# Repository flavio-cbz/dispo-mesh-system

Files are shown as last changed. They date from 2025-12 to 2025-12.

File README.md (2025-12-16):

# 📡 DispoMesh - Système de Disponibilité Connecté

  

**DispoMesh** est une solution intelligente et autonome pour visualiser en temps réel la disponibilité des collaborateurs dans un open-space ou des bureaux partagés. Fini les interruptions inutiles : un coup d'œil suffit pour savoir si votre collègue est disponible, occupé ou absent.

---

## ❓ La Problématique

Dans les écoles et laboratoires, les **enseignants-chercheurs** travaillant en open-space sont fréquemment sollicités par les étudiants, souvent au détriment de leur concentration.

* *"Est-ce que je peux entrer pour poser une question ?"*
* *"Le professeur est-il en pleine recherche ou disponible ?"*
* *"Est-il en réunion ou simplement concentré ?"*

Ces interruptions constantes par les élèves nuisent à la productivité et à la qualité du travail de recherche. Ça nuit à leur travail et ainsi qu'à tous les autres s'il n'est pas là.

---

## 🎯 Objectif du Projet

Créer un système **simple, visuel et décentralisé** permettant à chaque collaborateur d'indiquer son statut via un petit boîtier sur son bureau. Ces informations sont instantanément répercutées sur un **tableau de bord central** (mur d'écrans OLED) et une **interface web**.

### Les 3 États Clés

* 🟢 **DISPONIBLE** : "Vous pouvez venir me voir."
* 🔴 **OCCUPÉ** : "Je suis concentré / en réunion, ne pas déranger."
* 🟠 **ABSENT** : "Je ne suis pas à mon poste."

---

## 🏗️ Architecture & Fonctionnement

Le système repose sur un réseau **WiFi Mesh** (maillé) autonome. Il ne nécessite pas de connexion Internet ni d'infrastructure complexe.

### 1. Les Boîtiers "Slave" (Sur les bureaux)

Chaque collaborateur dispose d'un petit boîtier autonome.

* **Action** : Un simple bouton pour changer de statut.
* **Feedback** : Une LED (Verte/Rouge/Orange) et un petit écran confirment le statut actuel.
* **Intelligence** : Si vous oubliez de vous mettre en "Absent", le boîtier passe automatiquement en **Mode Éco** après 5 minutes d'inactivité.
* **Configuration facile** : Au premier démarrage, le boîtier crée un WiFi de config. Après configuration, il se connecte automatiquement au réseau.
* **Reset sans ordinateur** : Maintenir le bouton 5 secondes au démarrage pour réinitialiser la configuration.

### 2. Le Boîtier "Master" (À l'entrée ou au mur)

C'est le cerveau du système.

* **Affichage** : Un mur d'écrans OLED affiche la liste de tous les collaborateurs et leur statut en temps réel.
* **Dashboard Web** : Héberge un site web local accessible par tous pour voir les disponibilités depuis son smartphone ou PC.
* **Animation** : Effets visuels fluides et indicateurs LED pour une lecture rapide.

---

## ✨ Fonctionnalités Clés

* **🚀 Plug & Play** : Branchez, ça marche. Le réseau se crée tout seul.
* **⚡ Temps Réel** : Changement de statut instantané (< 100ms).
* **🔋 Économie d'Énergie** : Mise en veille automatique des écrans et processeurs.
* **📱 Interface Web Moderne** : Dark mode, responsive, QR Code pour connexion facile.
* **🛡️ Robuste** : Redémarrage automatique en cas de bug (Watchdog), reconnexion automatique au réseau.

---

## 🛠️ Comment le refaire chez soi ?

### Matériel Requis

Pour un kit de démarrage (1 Master + 1 Slave) :

* **2x ESP32 DevKit V1** (ou compatible).
* **5x Écrans OLED SSD1306** (128x32 pixels, I2C).
* **1x Multiplexeur I2C TCA9548A** (pour le Master, permet de brancher plusieurs écrans même adresse).
* **Ruban LED NeoPixel (WS2812B)** (au moins 6 LEDs).
* **1x Bouton Poussoir** (pour le Slave).
* **Câbles Dupont** et Breadboards.

### Câblage

#### 🔌 Master (Récepteur)

* **Écrans OLED** : Via le Multiplexeur TCA9548A (Adresse 0x70).
  * SDA ESP32 (D21) -> SDA TCA
  * SCL ESP32 (D22) -> SCL TCA
  * Écrans sur les canaux TCA : 0, 1, 2, 6, 7.
* **LEDs NeoPixel** : Pin **D27**.

#### 🔌 Slave (Émetteur)

* **Écran OLED** : Directement sur I2C.
  * SDA -> D21
  * SCL -> D22
* **Bouton** : Pin **D32** (avec Pull-down interne ou externe).
* **LED NeoPixel** : Pin **D27**.

### Installation Logicielle

#### Option A : Via PlatformIO (Recommandé)

1. **Pré-requis** :
   * [VS Code](https://code.visualstudio.com/)
   * Extension **PlatformIO IDE** pour VS Code.

2. **Cloner le projet** :

    ```bash
    git clone https://github.com/flavio-cbz/dispo-mesh-system.git
    cd dispo-mesh-system
    ```

3. **Bibliothèques (Gérées automatiquement par PlatformIO)** :
   * `painlessMesh` (v1.5.7)
   * `ArduinoJson` (v7.4.2)
   * `Adafruit SSD1306` (v2.5.9)
   * `Adafruit GFX Library` (v1.11.9)
   * `Adafruit NeoPixel` (v1.12.0)
   * `U8g2_for_Adafruit_GFX` (v1.0.2)

4. **Déployer** :
    Connectez vos ESP32 et utilisez le script de déploiement ou les tâches PlatformIO "Upload".

    ```bash
    ./deploy.sh
    ```

    Suivez les instructions à l'écran pour flasher le Master puis les Slaves.

#### Option B : Via Arduino IDE (Manuel)

Si vous préférez l'IDE Arduino classique :

1. Installez les bibliothèques listées ci-dessus via le **Gestionnaire de bibliothèques**.
2. Ouvrez `master_recepteur/src/master_recepteur.ino` pour le Master.
3. Ouvrez `slave_emetteur/src/slave_emetteur.ino` pour les Slaves.
4. Sélectionnez votre carte (ESP32 Dev Module) et le port, puis téléversez.

### 🖨️ Fichiers 3D à Imprimer

Les fichiers STL pour l'impression 3D des boîtiers sont disponibles dans le dossier `Modélisations 3D/` :

#### Émetteur (Slave)
* **[Emetteur_Base.STL](Modélisations%203D/Emetteur/Emetteur_Base.STL)** : Socle du boîtier émetteur.
* **[Emetteur_Boite.STL](Modélisations%203D/Emetteur/Emetteur_Boite.STL)** : Couvercle du boîtier émetteur.

#### Récepteur (Master)
* **[Recepteur_MAIN.STL](Modélisations%203D/Recepteur/Recepteur_MAIN.STL)** : Corps principal du récepteur.
* **[Recepteur_Add.STL](Modélisations%203D/Recepteur/Recepteur_Add.STL)** : Pièce additionnelle pour le récepteur.

> 💡 Les fichiers sources SolidWorks sont également disponibles dans `Modélisations 3D/Fichier Solidworks/`.

### 📸 Galerie

#### L'Émetteur (Slave)

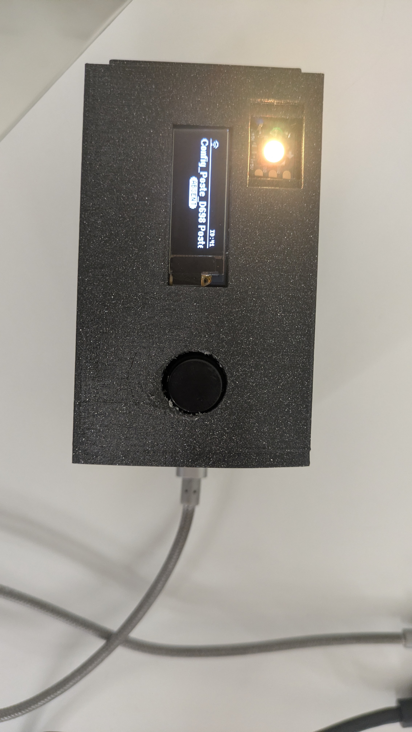
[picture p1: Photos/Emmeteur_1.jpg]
Emetteur Slave

*Le boîtier Slave avec son bouton et son écran de statut.*

#### Le Récepteur (Master)

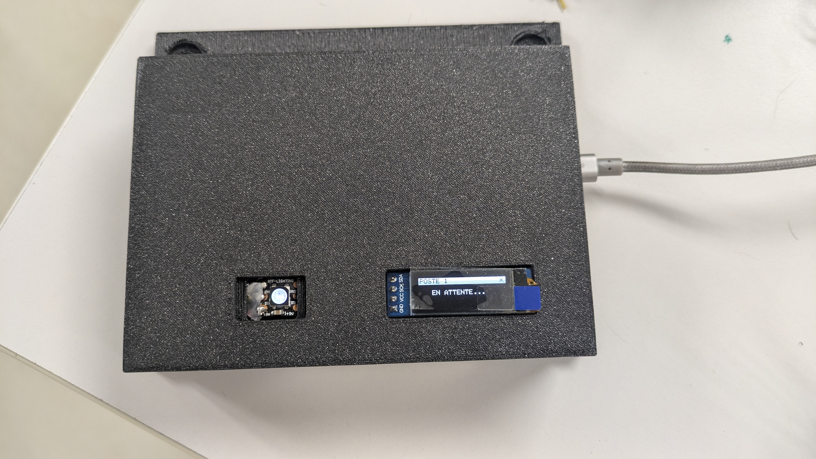
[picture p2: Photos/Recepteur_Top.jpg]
Récepteur Master

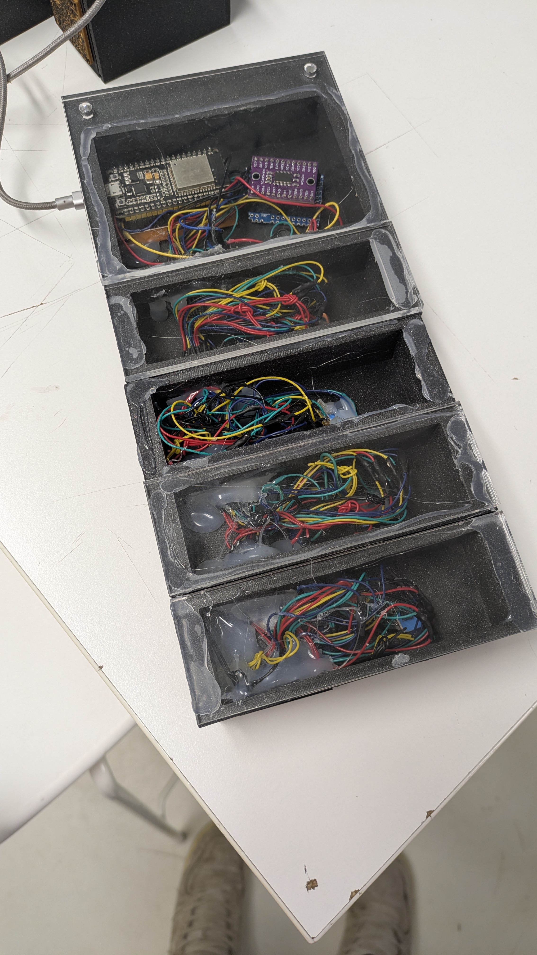
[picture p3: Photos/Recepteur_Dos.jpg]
Câblage Arrière

*Le Master et son câblage (Multiplexeur I2C visible à l'arrière).*

#### Montage Complet

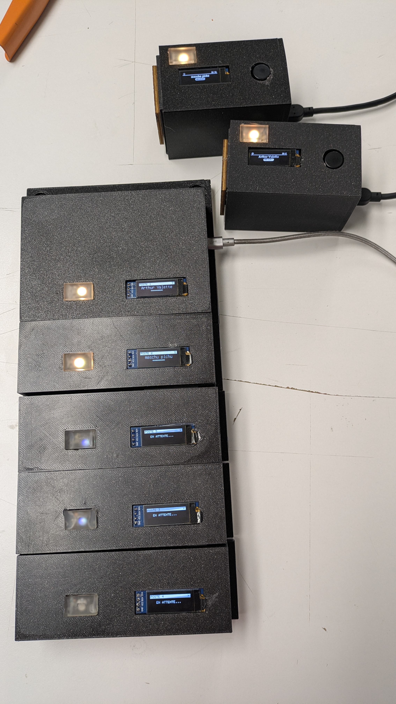
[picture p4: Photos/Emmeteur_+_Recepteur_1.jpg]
Système Complet

*Vue d'ensemble du système DispoMesh en fonctionnement.*

### 🎥 Démos Vidéo

#### Fonctionnement Général

<video src="Photos/Demo_courte_recepteur.mp4" controls width="100%"></video>

#### Démonstration du Reset

<video src="Photos/Demo_Reset.mp4" controls width="100%"></video>

4. **Profiter !**
    Les boîtiers se connectent entre eux automatiquement. Connectez-vous au WiFi `DispoMesh` (mot de passe: `meshpass2025`) pour accéder au dashboard.

---

## 📚 Documentation

* Pour les détails techniques approfondis (architecture code, protocole JSON, hardware), consultez la [Documentation Technique](DOCUMENTATION_TECHNIQUE.md).

---

## 📄 Licence

Ce projet est open-source sous licence **MIT**. Sentez-vous libre de le modifier, l'améliorer et le partager !

---
*Développé par Flavio COMBLEZ pour simplifier la vie de bureau.*

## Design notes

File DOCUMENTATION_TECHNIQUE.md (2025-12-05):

# Documentation Technique - DispoMesh v6.0

## 1. Vue d'Ensemble du Système

**DispoMesh** est un système de signalétique de disponibilité distribué basé sur des microcontrôleurs ESP32 communiquant via un réseau maillé (Mesh).

Le système est composé de deux types d'unités :

1. **Le Master (Récepteur)** : Unité centrale qui agrège les données, héberge le tableau de bord web et affiche les statuts sur un mur d'écrans OLED.
2. **Les Slaves (Émetteurs)** : Boîtiers individuels placés sur les bureaux, permettant aux utilisateurs de changer leur statut via un bouton physique.

### Architecture Logique

```mermaid
graph TD
    S1[Slave 1] <-->|Mesh JSON| M[Master Node]
    S2[Slave 2] <-->|Mesh JSON| M
    S3[Slave 3] <-->|Mesh JSON| M
    M -->|I2C Multiplexé| D[Mur d'Écrans OLED]
    M -->|HTTP/REST| W[Dashboard Web]
    U[Utilisateur] -->|Bouton| S1
```

---

## 2. Le Nœud Maître (Master Récepteur)

Le Master est le cerveau du système. Il est configuré comme le nœud **ROOT** du réseau maillé, ce qui stabilise la topologie du réseau.

### 2.1 Gestion des Écrans (Multiplexage I2C)

Le Master gère jusqu'à 5 écrans OLED simultanément. Comme les écrans OLED ont tous la même adresse I2C (`0x3C`), un multiplexeur **TCA9548A** est utilisé.

* **Fichier** : `master_recepteur.ino`
* **Fonction clé** : `tcaSelect(uint8_t i)`
* **Logique** : Avant chaque commande de dessin, le code sélectionne le canal I2C approprié sur le multiplexeur.
* **Hot-Plug** : La fonction `checkScreens()` vérifie périodiquement (toutes les 5s) la présence physique des écrans pour éviter de bloquer le bus I2C si un écran est débranché.

### 2.2 Serveur Web & Interface (SPIFFS)

L'interface utilisateur n'est pas codée en dur dans le C++. Elle est stockée dans la mémoire flash du système de fichiers (SPIFFS).

* **Structure** :
  * `/index.html` : Structure HTML5 moderne.
  * `/style.css` : Styles "Glassmorphism" et animations.
  * `/script.js` : Logique frontend (récupération des données API).
* **API REST** : Le Master expose l'endpoint `/api/data` qui renvoie un JSON complet contenant l'état de tous les slots, l'historique et l'uptime.

### 2.3 Robustesse & Watchdog

Pour garantir un fonctionnement 24/7 :

* **Hardware Watchdog** : Si la boucle principale (`loop`) se bloque plus de 10 secondes, l'ESP32 redémarre automatiquement.
* **Heartbeat Monitor** : Le Master surveille les battements de cœur des Slaves. Si un Slave ne donne pas signe de vie pendant 60 secondes (`HEARTBEAT_TIMEOUT_MS`), il est marqué comme déconnecté.

### 2.4 Économiseur d'Écran (Screen Saver)

Pour éviter le marquage des écrans OLED (burn-in) et réduire la consommation :

* Si aucune activité (message Mesh reçu ou appel API) n'est détectée pendant 10 minutes, les écrans s'éteignent et les LEDs diminuent d'intensité.
* Le réveil est instantané au moindre événement.

---

## 3. Le Nœud Esclave (Slave Émetteur)

Le Slave est conçu pour être autonome et économe en énergie.

### 3.1 Initialisation & Configuration

Le Slave possède deux modes de démarrage selon son état de configuration :

#### Mode Configuration (Premier démarrage ou après reset)

Si le Slave **n'est pas configuré** :

* 🔵 LED bleue clignotante
* Écran affiche "MODE CONFIG" avec le SSID WiFi
* Un point d'accès WiFi visible est créé (`Config_Poste_XXXX`)
* **Le mesh NE démarre PAS** - pas de connexion au Master
* Après configuration via l'interface web → redémarrage automatique

#### Mode Normal

Si le Slave **est déjà configuré** :

* Démarrage normal avec connexion au mesh
* Panneau de configuration WiFi masqué

#### Reset de la Configuration

Pour **réinitialiser** un Slave (équivalent à un re-upload du code) :

1. Maintenir le **bouton enfoncé pendant 5 secondes au démarrage**
2. 🟠 LED orange clignotante + compte à rebours sur l'écran
3. Après 5 secondes : 🟣 LED magenta + "CONFIG RESET!"
4. La configuration est effacée et le Slave passe en mode configuration

> **Note** : Cette fonctionnalité permet de reconfigurer un Slave sur le terrain sans ordinateur.

### 3.2 Gestion des États

L'utilisateur change son statut via un bouton poussoir unique.

* **États** : Disponible (Vert) -> Occupé (Rouge) -> Absent (Orange).
* **Feedback** : Une LED NeoPixel et un écran OLED local confirment l'état.

### 3.3 Mode Éco (Deep Power Saving)

Si l'utilisateur reste en statut "ABSENT" pendant plus de 5 minutes, le Slave entre en mode économie d'énergie agressif :

1. **CPU Downclocking** : La fréquence du processeur passe de 240MHz à 80MHz.
2. **WiFi Power Save** : Activation du mode `WIFI_PS_MIN_MODEM`.
3. **Dimming** : La luminosité des LEDs est réduite au minimum.

### 3.4 Communication

* **Heartbeat** : Envoie un message `heartbeat` toutes les 30 secondes pour dire au Master "Je suis vivant".
* **Broadcast** : Envoie un message `status` immédiatement lors d'un appui bouton.

---

## 4. Protocole de Communication (JSON)

Les échanges se font via des paquets JSON légers sur le réseau `painlessMesh`.

### Types de Messages

**1. Enregistrement (`register`)**
Envoyé par le Slave au démarrage pour s'associer à un slot.

```json
{
  "type": "register",
  "prenom": "Jean",
  "nom": "Dupont",
  "etat": 0
}
```

**2. Mise à jour de Statut (`status`)**
Envoyé lors d'un appui bouton.

```json
{
  "type": "status",
  "etat": 1
}
```

**3. Battement de Cœur (`heartbeat`)**
Envoyé périodiquement.

```json
{
  "type": "heartbeat",
  "slotId": 2,
  "etat": 1,
  "eco": false
}
```

---

## 5. Guide de Déploiement

Un script automatisé `deploy.sh` facilite la mise à jour des boîtiers.

### Pré-requis

* PlatformIO Core (CLI) installé.
* Drivers USB-Série (CH340 ou CP210x) installés.

### Procédure

1. Connecter le Master en USB.
2. Lancer `./deploy.sh`.
3. Sélectionner le port du Master. Le script va :
    * Créer l'image du système de fichiers (SPIFFS) avec les fichiers web.
    * Téléverser le SPIFFS.
    * Compiler et téléverser le Firmware.
4. Connecter ensuite les Slaves un par un et suivre les instructions du script.

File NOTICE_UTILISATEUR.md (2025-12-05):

# 📋 Notice d'Utilisation

## Votre boîtier de disponibilité

---

## 🎨 Les 3 états

| Couleur | Signification |
|---|---|
| 🟢 **Vert** | Je suis disponible |
| 🔴 **Rouge** | Ne pas déranger |
| 🟠 **Orange** | Je suis absent |

---

## 🔘 Changer votre statut

**Appuyez sur le bouton** pour passer à l'état suivant.

---

## Première utilisation

1. L'écran affiche **"MODE CONFIG"** avec un nom de réseau WiFi
2. Connectez-vous à ce WiFi depuis votre téléphone
3. Mot de passe : **config2025**
4. Entrez votre **Prénom** et **Nom** dans la page qui s'affiche
5. Le boîtier redémarre : c'est prêt !

---

## Changer de nom

Pour reconfigurer le boîtier :

1. Débranchez-le
2. Maintenez le bouton appuyé
3. Rebranchez en gardant le bouton enfoncé **5 secondes**
4. Le boîtier se réinitialise, recommencez la configuration

---

*En cas de problème, contactez votre administrateur.*

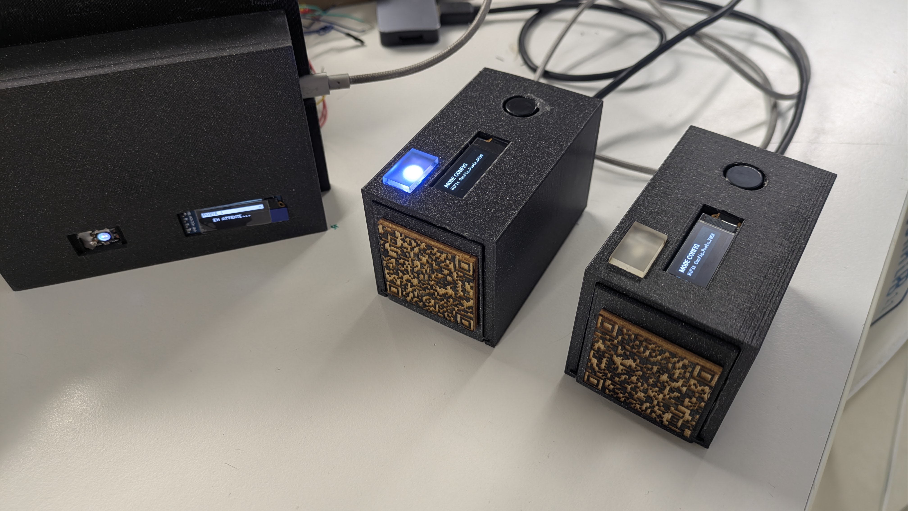
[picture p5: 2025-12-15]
Photos/Pres_1.jpg

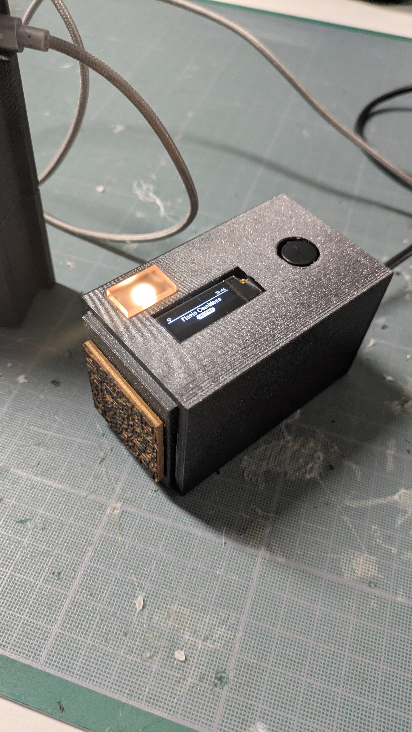
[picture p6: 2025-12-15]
Photos/Emmeteur_2.jpg

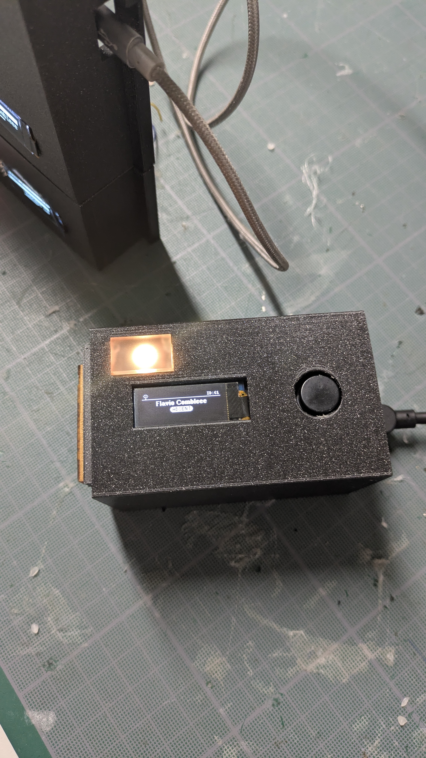
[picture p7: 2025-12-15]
Photos/Emmeteur_3.jpg

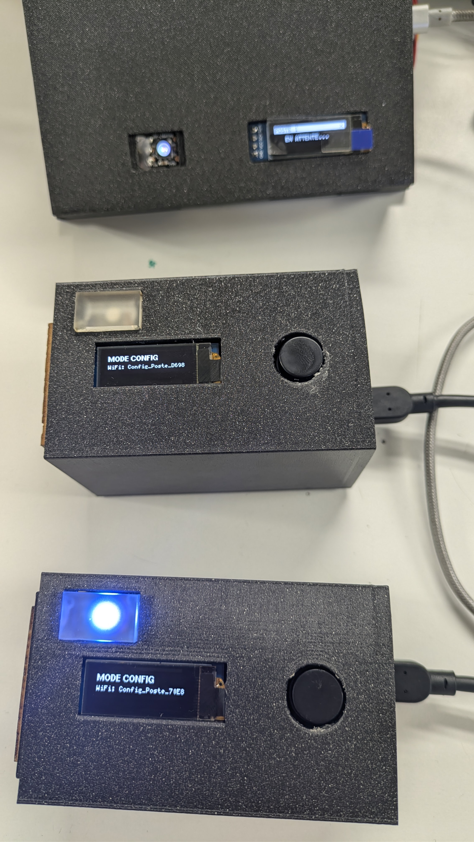
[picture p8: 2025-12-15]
Photos/Emmeteur_+_Recepteur_3.jpg

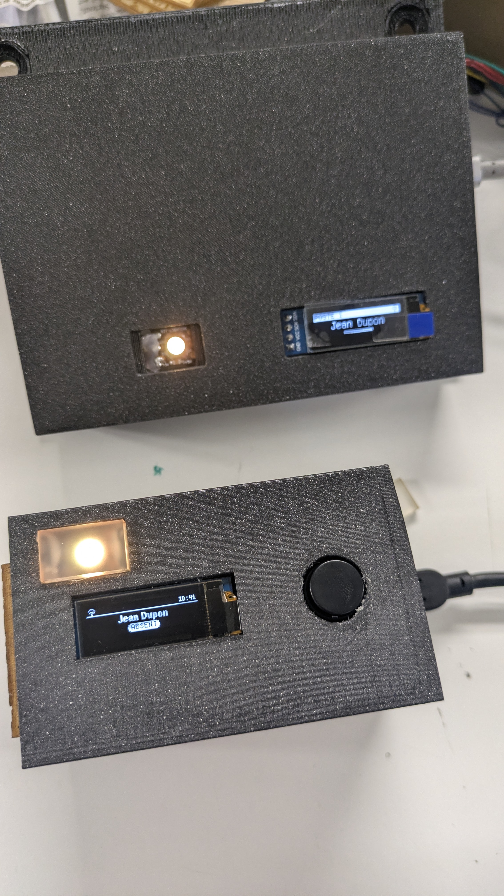
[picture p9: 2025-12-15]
Photos/Emmeteur_+_Recepteur_4.jpg

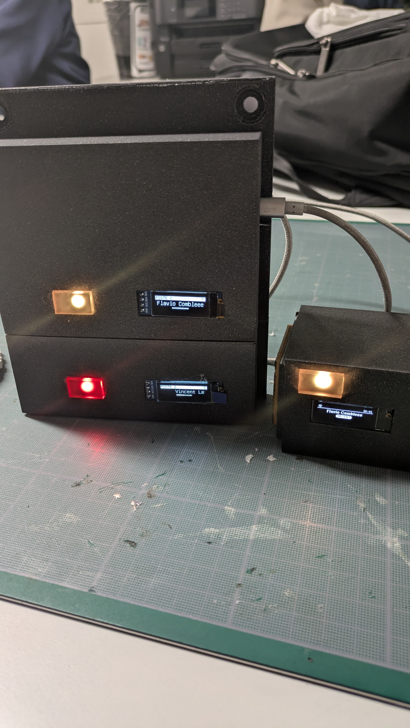
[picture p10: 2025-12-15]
Photos/Emmeteur_+_Recepteur_2.jpg

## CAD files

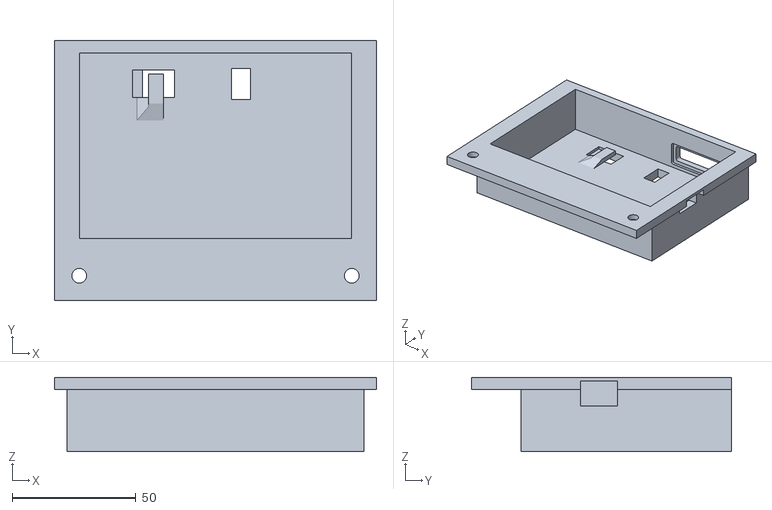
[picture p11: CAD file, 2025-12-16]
Modélisations 3D/Recepteur/Recepteur_MAIN.STL
130.0 x 105.0 x 30.0

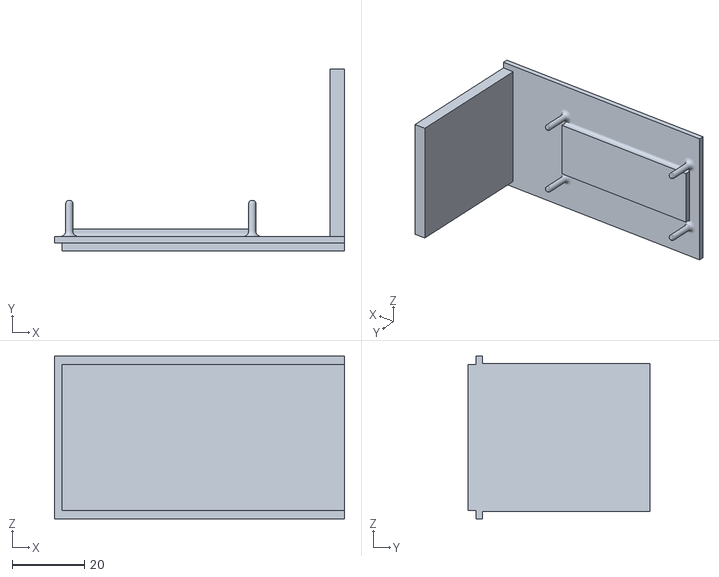
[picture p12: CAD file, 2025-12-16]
Modélisations 3D/Emetteur/Emetteur_Base.STL
80.2 x 50.3 x 45.0

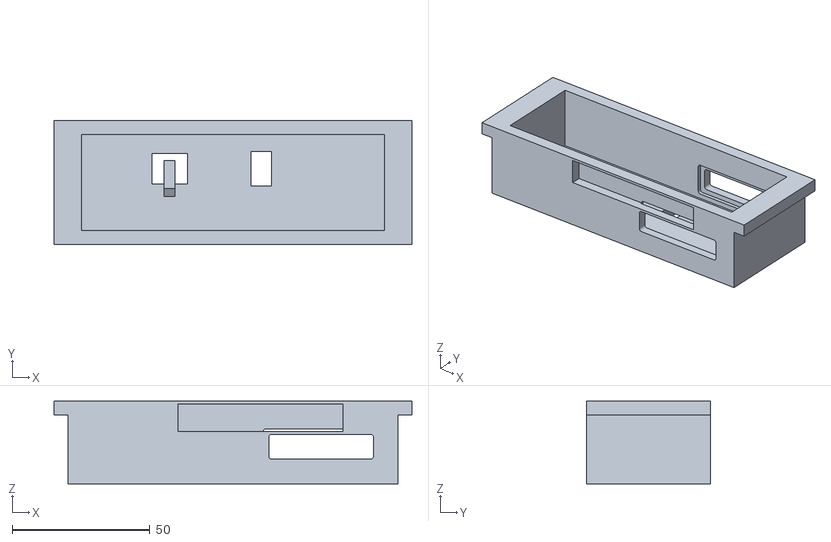
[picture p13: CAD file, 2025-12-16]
Modélisations 3D/Recepteur/Recepteur_Add.STL
130.0 x 45.0 x 30.0

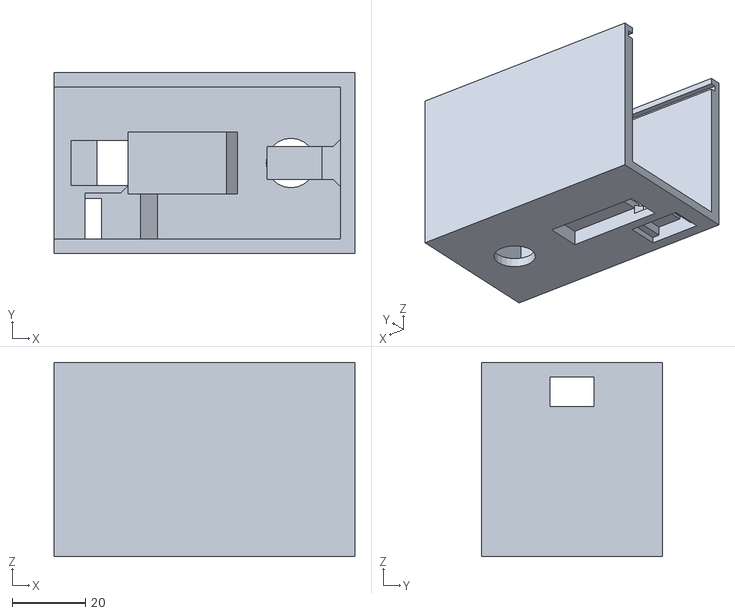
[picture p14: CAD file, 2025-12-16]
Modélisations 3D/Emetteur/Emetteur_Boite.STL
82.2 x 49.5 x 53.0

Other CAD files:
Modélisations 3D/Fichier Solidworks/Piece 1.SLDPRT
Modélisations 3D/Fichier Solidworks/Piece 2.SLDPRT
Modélisations 3D/Fichier Solidworks/Piece 4.SLDPRT
Modélisations 3D/Fichier Solidworks/Piece 3.SLDPRT

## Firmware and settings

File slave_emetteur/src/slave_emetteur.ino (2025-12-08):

/*
 * ═══════════════════════════════════════════════════════════════════════
 * ESP32 SLAVE ÉMETTEUR - DispoMesh v5.7 FINAL - FIX INIT & CONFIG
 * ═══════════════════════════════════════════════════════════════════════
 * - BROWNOUT : DÉSACTIVÉ (Stabilité)
 * - WIFI : MASQUÉ (Variable HIDE_NETWORKS = 1)
 * - UI : Badge iOS + Icônes
 * - RESEAU : Dual Stack (Mesh + Config AP) sur même canal
 * ═══════════════════════════════════════════════════════════════════════
 */

#include <Adafruit_NeoPixel.h>
#include <Adafruit_SSD1306.h>
#include <ArduinoJson.h>
#include <DNSServer.h>
#include <SPIFFS.h>
#include <U8g2_for_Adafruit_GFX.h>
#include <WebServer.h>
#include <WiFi.h>
#include <Wire.h>
#include <painlessMesh.h>

// MODULES CRITIQUES (Anti-Brownout)
#include "soc/rtc_cntl_reg.h"
#include "soc/soc.h"

// MODULES ÉCONOMIE D'ÉNERGIE
#include "esp_wifi.h"
#include <esp_pm.h>
#include <esp_task_wdt.h>

// 🔒 CONFIGURATION SÉCURITÉ
#define HIDE_NETWORKS 1 // 1 = Masqué, 0 = Visible

// ⚡ CONFIGURATION ÉCONOMIE D'ÉNERGIE
#define ECO_MODE_DELAY_MS 300000    // 5 minutes en ABSENT avant mode éco
#define HEARTBEAT_INTERVAL_MS 30000 // Heartbeat toutes les 30 secondes
#define LED_BRIGHTNESS_NORMAL 40
#define LED_BRIGHTNESS_ECO 8
#define CPU_FREQ_NORMAL 240 // MHz
#define CPU_FREQ_ECO 80     // MHz

// CONFIGURATION MATÉRIEL
#define BTN_PIN 32
#define PIN_NEOPIXEL 27
#define NUM_PIXELS 1

#define SCREEN_WIDTH 128
#define SCREEN_HEIGHT 32
#define OLED_ADDR 0x3C

Adafruit_NeoPixel pixel(NUM_PIXELS, PIN_NEOPIXEL, NEO_GRB + NEO_KHZ800);
Adafruit_SSD1306 display(SCREEN_WIDTH, SCREEN_HEIGHT, &Wire, -1);
U8G2_FOR_ADAFRUIT_GFX u8g2;

const uint32_t COLOR_DISPO = pixel.Color(0, 255, 0);
const uint32_t COLOR_BUSY = pixel.Color(255, 0, 0);
const uint32_t COLOR_AWAY = pixel.Color(255, 140, 0);

// VARIABLES GLOBALES
#define MESH_PREFIX "DispoMesh"
#define MESH_PASSWORD "meshpass2025"
#define MESH_PORT 5555

// 🔧 CONFIGURATION RESET
#define RESET_HOLD_TIME_MS 5000 // 5 secondes pour reset config

SemaphoreHandle_t xMutex;
char apSSID[32];
String monPrenom = "Nouveau";
String monNom = "Poste";
int etatActuel = 2;
int slotId = -1;
volatile bool configSauvegardee = false;
bool meshInitialized = false;
volatile bool needsRegister = false; // Flag pour re-registration différé
bool isConfigured = false;           // Flag indiquant si le poste est configuré
bool configModeActive = false; // Flag indiquant si on est en mode configuration

// ⚡ Variables mode économie d'énergie
unsigned long lastStateChange = 0; // Timestamp du dernier changement d'état
unsigned long lastHeartbeat = 0;   // Timestamp du dernier heartbeat
bool ecoModeActive = false;        // Mode économie activé
uint8_t currentBrightness = LED_BRIGHTNESS_NORMAL;

Scheduler userScheduler;
painlessMesh mesh;
WebServer server(80);
DNSServer dnsServer;

// ═══════════════════════════════════════════════════════════════════════
// UI OLED
// ═══════════════════════════════════════════════════════════════════════
const unsigned char icon_wifi[] PROGMEM = {0x3C, 0x42, 0x81, 0x3C,
                                           0x42, 0x18, 0x00, 0x18};

void updateLocalDisplay() {
  display.clearDisplay();
  u8g2.setForegroundColor(SSD1306_WHITE);

  // Header
  display.drawLine(0, 8, SCREEN_WIDTH, 8, SSD1306_WHITE);
  if (slotId != -1)
    display.drawBitmap(2, 0, icon_wifi, 8, 8, SSD1306_WHITE);

  u8g2.setFont(u8g2_font_4x6_tr);
  String idTxt = "ID:" + String(mesh.getNodeId() % 100);
  u8g2.drawUTF8(SCREEN_WIDTH - u8g2.getUTF8Width(idTxt.c_str()) - 2, 6,
                idTxt.c_str());

  // Nom
  u8g2.setFont(u8g2_font_helvB08_tf);
  String fullName = monPrenom + " " + monNom;
  int xName = (SCREEN_WIDTH - u8g2.getUTF8Width(fullName.c_str())) / 2;
  if (xName < 0)
    xName = 0;
  u8g2.drawUTF8(xName, 20, fullName.c_str());

  // Badge Statut
  String statusTxt;
  switch (etatActuel) {
  case 0:
    statusTxt = "DISPONIBLE";
    break;
  case 1:
    statusTxt = "OCCUPE";
    break;
  default:
    statusTxt = "ABSENT";
    break;
  }

  u8g2.setFont(u8g2_font_5x7_tf);
  int wStatus = u8g2.getUTF8Width(statusTxt.c_str()) + 8;
  int xStatus = (SCREEN_WIDTH - wStatus) / 2;

  display.fillRoundRect(xStatus, 23, wStatus, 9, 4, SSD1306_WHITE);
  u8g2.setForegroundColor(SSD1306_BLACK);
  u8g2.setBackgroundColor(SSD1306_WHITE);
  u8g2.drawUTF8(xStatus + 4, 30, statusTxt.c_str());
  u8g2.setForegroundColor(SSD1306_WHITE);
  u8g2.setBackgroundColor(SSD1306_BLACK);

  display.display();
}

void updateLEDs() {
  pixel.clear();
  if (slotId == -1) {
    // Clignotement rouge quand non connecté
    if ((millis() / 500) % 2) {
      pixel.setPixelColor(0, COLOR_BUSY);
    } else {
      pixel.setPixelColor(0, 0); // OFF pour le clignotement
    }
  } else {
    switch (etatActuel) {
    case 0:
      pixel.setPixelColor(0, COLOR_DISPO);
      break;
    case 1:
      pixel.setPixelColor(0, COLOR_BUSY);
      break;
    default:
      pixel.setPixelColor(0, COLOR_AWAY);
      break;
    }
  }
  pixel.show();
}

// ═══════════════════════════════════════════════════════════════════════
// SYSTÈME
// ═══════════════════════════════════════════════════════════════════════
void initSSID() {
  // Utiliser ESP.getEfuseMac() pour obtenir une MAC stable AVANT l'init WiFi
  uint64_t chipid = ESP.getEfuseMac();
  uint8_t mac[6];
  mac[0] = (chipid >> 0) & 0xFF;
  mac[1] = (chipid >> 8) & 0xFF;
  mac[2] = (chipid >> 16) & 0xFF;
  mac[3] = (chipid >> 24) & 0xFF;
  mac[4] = (chipid >> 32) & 0xFF;
  mac[5] = (chipid >> 40) & 0xFF;

  snprintf(apSSID, sizeof(apSSID), "Config_Poste_%02X%02X", mac[4], mac[5]);
  Serial.printf("[INIT] MAC eFuse: %02X:%02X:%02X:%02X:%02X:%02X\n", mac[0],
                mac[1], mac[2], mac[3], mac[4], mac[5]);
  Serial.printf("[INIT] SSID généré: %s\n", apSSID);
}

void sauvegarderNom(String p, String n) {
  // Validation: ne pas sauvegarder si le prénom ressemble à un SSID
  if (p.startsWith("Config_Poste_") || p.length() == 0) {
    Serial.println(
        "[CONFIG] ERREUR: Tentative de sauvegarde d'un nom invalide!");
    return;
  }

  Serial.printf("[CONFIG] Sauvegarde nom: '%s' '%s'\n", p.c_str(), n.c_str());

  File f = SPIFFS.open("/config.json", "w");
  if (f) {
    StaticJsonDocument<256> doc;
    doc["p"] = p;
    doc["n"] = n;
    doc["configured"] = true; // Flag explicite de configuration
    serializeJson(doc, f);
    f.close();
    Serial.println("[CONFIG] Configuration sauvegardée avec succès");

    // Marquer comme configuré
    isConfigured = true;
  } else {
    Serial.println("[CONFIG] ERREUR: Impossible d'ouvrir le fichier config!");
  }
  updateLocalDisplay();
}

bool chargerNom() {
  Serial.println("[CONFIG] Chargement de la configuration...");

  if (SPIFFS.exists("/config.json")) {
    File f = SPIFFS.open("/config.json", "r");
    if (f) {
      StaticJsonDocument<256> doc;
      DeserializationError err = deserializeJson(doc, f);

      if (err == DeserializationError::Ok) {
        String p = doc["p"] | "";
        String n = doc["n"] | "";
        bool configured = doc["configured"] | false;

        Serial.printf("[CONFIG] Lu: prenom='%s', nom='%s', configured=%d\n",
                      p.c_str(), n.c_str(), configured);

        // Vérifier que le prénom n'est pas vide ou égal à l'SSID par défaut
        if (p.length() > 0 && !p.startsWith("Config_Poste_") &&
            !p.startsWith("Nouveau")) {
          monPrenom = p;
          monNom = n;
          f.close();
          Serial.printf("[CONFIG] Configuration valide chargée: %s %s\n",
                        monPrenom.c_str(), monNom.c_str());
          return true; // Configuration valide trouvée
        } else {
          Serial.println("[CONFIG] Prénom invalide dans la config");
        }
      } else {
        Serial.printf("[CONFIG] Erreur JSON: %s\n", err.c_str());
      }
      f.close();
    }
  } else {
    Serial.println("[CONFIG] Fichier config.json non trouvé");
  }

  // PAS de configuration valide - garder les valeurs par défaut
  // NE PAS affecter apSSID au prénom!
  monPrenom = "Nouveau";
  monNom = "Poste";
  Serial.printf(
      "[CONFIG] Pas de config valide, utilisation par défaut: %s %s\n",
      monPrenom.c_str(), monNom.c_str());
  return false; // Pas de configuration valide
}

// Fonction pour effacer la configuration
void effacerConfig() {
  if (SPIFFS.exists("/config.json")) {
    SPIFFS.remove("/config.json");
    Serial.println("[CONFIG] Configuration effacée");
  }
  // NE PAS affecter apSSID au prénom!
  monPrenom = "Nouveau";
  monNom = "Poste";
  isConfigured = false;
  Serial.printf("[CONFIG] Réinitialisé à: %s %s\n", monPrenom.c_str(),
                monNom.c_str());
}

// ═══════════════════════════════════════════════════════════════════════
// WEB SERVER
// ═══════════════════════════════════════════════════════════════════════
const char HTML_PAGE[] PROGMEM = R"rawliteral(
<!DOCTYPE html>
<html lang="fr">
<head>
    <meta charset="UTF-8">
    <meta name="viewport" content="width=device-width, initial-scale=1.0">
    <title>Configuration Poste</title>
    <style>
        body { font-family: -apple-system, BlinkMacSystemFont, "Segoe UI", Roboto, Helvetica, Arial, sans-serif; background: #1a1a2e; color: #fff; display: flex; flex-direction: column; align-items: center; min-height: 100vh; margin: 0; padding: 20px; }
        .card { background: rgba(255, 255, 255, 0.05); padding: 30px; border-radius: 20px; width: 100%; max-width: 350px; backdrop-filter: blur(10px); border: 1px solid rgba(255, 255, 255, 0.1); box-shadow: 0 8px 32px 0 rgba(0, 0, 0, 0.37); }
        h2 { margin-top: 0; font-weight: 300; letter-spacing: 1px; text-align: center; margin-bottom: 20px; }
        .input-group { margin-bottom: 15px; }
        label { display: block; margin-bottom: 5px; font-size: 0.8rem; color: rgba(255, 255, 255, 0.6); }
        input { width: 100%; padding: 12px; background: rgba(0, 0, 0, 0.2); border: 1px solid rgba(255, 255, 255, 0.1); border-radius: 8px; color: #fff; font-size: 1rem; outline: none; transition: border-color 0.3s; box-sizing: border-box; }
        input:focus { border-color: #4ade80; }
        button { width: 100%; padding: 14px; background: linear-gradient(135deg, #4ade80 0%, #22c55e 100%); color: #000; border: none; border-radius: 8px; font-weight: 600; font-size: 1rem; cursor: pointer; transition: transform 0.2s, opacity 0.2s; margin-top: 10px; }
        button:active { transform: scale(0.98); }
        .status-box { margin-top: 25px; padding-top: 20px; border-top: 1px solid rgba(255, 255, 255, 0.1); }
        .status-item { display: flex; justify-content: space-between; margin-bottom: 8px; font-size: 0.9rem; }
        .status-val { font-weight: 500; }
        .connected { color: #4ade80; }
        .disconnected { color: #f87171; }
        .qr-panel { background: #fff; color: #000; padding: 15px; border-radius: 10px; margin-top: 20px; text-align: center; }
        .qr-title { font-size: 0.8rem; font-weight: 700; margin-bottom: 5px; opacity: 0.7; }
        .qr-ssid { font-family: monospace; font-size: 1.1rem; font-weight: bold; }
        .qr-pass { font-family: monospace; font-size: 0.9rem; color: #555; }
    </style>
</head>
<body>
    <div class="card">
        <h2>CONFIG POSTE</h2>
        <form id="f">
            <div class="input-group">
                <label>Prénom</label>
                <input name="prenom" placeholder="Ex: Jean" required>
            </div>
            <div class="input-group">
                <label>Nom</label>
                <input name="nom" placeholder="Ex: Dupont" required>
            </div>
            <button type="submit">ENREGISTRER</button>
        </form>

        <div class="status-box">
            <div class="status-item">
                <span>État Mesh</span>
                <span class="status-val" id="mesh-status">...</span>
            </div>
            <div class="status-item">
                <span>Slot ID</span>
                <span class="status-val" id="slot-id">...</span>
            </div>
        </div>

        <div class="qr-panel">
            <div class="qr-title">WIFI CONFIGURATION</div>
            <div class="qr-ssid" id="ssid-disp">Config_Poste_XX</div>
            <div class="qr-pass">Pass: config2025</div>
        </div>
    </div>

    <script>
        fetch('/api/get').then(r => r.json()).then(d => {
            document.querySelector('[name="prenom"]').value = d.prenom;
            document.querySelector('[name="nom"]').value = d.nom;
            document.getElementById('ssid-disp').textContent = d.ssid || 'Config_Poste_XX';
            
            const meshSt = document.getElementById('mesh-status');
            if(d.meshConnected) {
                meshSt.textContent = "CONNECTÉ";
                meshSt.className = "status-val connected";
            } else {
                meshSt.textContent = "DÉCONNECTÉ";
                meshSt.className = "status-val disconnected";
            }
            
            document.getElementById('slot-id').textContent = (d.slotId !== -1) ? ("POSTE " + (d.slotId + 1)) : "NON ASSIGNÉ";
        });
        
        document.getElementById('f').onsubmit = e => {
            e.preventDefault();
            const btn = document.querySelector('button');
            const orig = btn.innerText;
            btn.innerText = 'SAUVEGARDE...';
            fetch('/api/save', { method: 'POST', body: new URLSearchParams(new FormData(e.target)) })
                .then(() => { 
                    btn.innerText = 'OK !'; 
                    setTimeout(() => btn.innerText = orig, 2000);
                })
                .catch(() => btn.innerText = 'ERREUR');
        };
    </script>
</body>
</html>
)rawliteral";

void setupWebServer() {
  server.on("/", []() { server.send_P(200, "text/html", HTML_PAGE); });
  server.on("/api/get", []() {
    StaticJsonDocument<256> d;

    // Ne pas pré-remplir avec des valeurs par défaut non valides
    String displayPrenom = monPrenom;
    String displayNom = monNom;

    // Si c'est un nom par défaut, laisser vide pour que l'utilisateur saisisse
    if (displayPrenom.startsWith("Config_Poste_") ||
        displayPrenom == "Nouveau" || displayPrenom.length() == 0) {
      displayPrenom = "";
      displayNom = "";
    }

    d["prenom"] = displayPrenom;
    d["nom"] = displayNom;
    d["ssid"] = String(apSSID);
    d["meshConnected"] = !mesh.getNodeList().empty();
    d["slotId"] = slotId;
    d["isConfigured"] = isConfigured;
    String s;
    serializeJson(d, s);
    server.send(200, "application/json", s);
  });
  server.on("/api/save", []() {
    String p = server.arg("prenom");
    String n = server.arg("nom");
    p.trim();
    n.trim();

    Serial.printf("[API] Requête save: prenom='%s', nom='%s'\n", p.c_str(),
                  n.c_str());

    // Validation: ne pas accepter de prénom vide ou ressemblant à un SSID
    if (p.length() == 0) {
      Serial.println("[API] ERREUR: Prénom vide");
      server.send(400, "text/plain", "Prénom requis");
      return;
    }
    if (p.startsWith("Config_Poste_")) {
      Serial.println("[API] ERREUR: Prénom invalide (ressemble à SSID)");
      server.send(400, "text/plain", "Prénom invalide");
      return;
    }

    // Sauvegarder d'abord dans le fichier
    sauvegarderNom(p, n);

    // Puis mettre à jour les variables globales avec mutex
    if (xSemaphoreTake(xMutex, 100)) {
      monPrenom = p;
      monNom = n;
      configSauvegardee = true;
      xSemaphoreGive(xMutex);
      Serial.printf("[API] Configuration mise à jour: %s %s\n", p.c_str(),
                    n.c_str());
      server.send(200, "text/plain", "OK");
    } else {
      Serial.println("[API] ERREUR: Impossible de prendre le mutex");
      server.send(500, "text/plain", "Erreur interne");
    }
  });

  // Gestionnaire pour les pages non trouvées (Captive Portal)
  server.onNotFound([]() { server.send_P(200, "text/html", HTML_PAGE); });

  server.begin();
}

void sendRegister() {
  StaticJsonDocument<256> doc;
  doc["type"] = "register";

  String p, n;
  // Tentative de prise de mutex avec timeout plus long (500ms)
  if (xSemaphoreTake(xMutex, 500)) {
    p = monPrenom;
    n = monNom;
    xSemaphoreGive(xMutex);
  } else {
    Serial.println(
        "[SLAVE] ERREUR: Mutex occupé, envoi annulé pour éviter 'null'");
    return;
  }

  doc["prenom"] = p;
  doc["nom"] = n;
  doc["etat"] = etatActuel;

  String msg;
  serializeJson(doc, msg);
  mesh.sendBroadcast(msg);
}

// 💓 Envoi heartbeat périodique au master
void sendHeartbeat() {
  if (slotId == -1)
    return; // Pas de heartbeat si non assigné

  StaticJsonDocument<128> doc;
  doc["type"] = "heartbeat";
  doc["slotId"] = slotId;
  doc["etat"] = etatActuel;
  doc["eco"] = ecoModeActive;

  String msg;
  serializeJson(doc, msg);
  mesh.sendBroadcast(msg);
  Serial.println("[HEARTBEAT] Envoyé");
}

// ⚡ Gestion du mode économie d'énergie
void checkEcoMode() {
  bool shouldBeEco = (etatActuel == 2) &&
                     (millis() - lastStateChange > ECO_MODE_DELAY_MS) &&
                     (slotId != -1); // Seulement si connecté

  if (shouldBeEco && !ecoModeActive) {
    // Activation mode éco
    ecoModeActive = true;
    Serial.println("[ECO] Mode économie ACTIVÉ");

    // Réduire luminosité LED
    currentBrightness = LED_BRIGHTNESS_ECO;
    pixel.setBrightness(currentBrightness);

    // Réduire fréquence CPU
    setCpuFrequencyMhz(CPU_FREQ_ECO);
    Serial.printf("[ECO] CPU: %d MHz\n", getCpuFrequencyMhz());

    // Activer WiFi power save
    esp_wifi_set_ps(WIFI_PS_MIN_MODEM);

  } else if (!shouldBeEco && ecoModeActive) {
    // Désactivation mode éco
    ecoModeActive = false;
    Serial.println("[ECO] Mode économie DÉSACTIVÉ");

    // Restaurer luminosité LED
    currentBrightness = LED_BRIGHTNESS_NORMAL;
    pixel.setBrightness(currentBrightness);

    // Restaurer fréquence CPU
    setCpuFrequencyMhz(CPU_FREQ_NORMAL);
    Serial.printf("[ECO] CPU: %d MHz\n", getCpuFrequencyMhz());

    // Désactiver WiFi power save pour réactivité
    esp_wifi_set_ps(WIFI_PS_NONE);
  }
}

// ═══════════════════════════════════════════════════════════════════════
// TÂCHES PRINCIPALES
// ═══════════════════════════════════════════════════════════════════════
void receivedCallback(uint32_t from, String &msg) {
  Serial.printf("[SLAVE] Message reçu de %u: %s\n", from, msg.c_str());

  StaticJsonDocument<512> doc;
  if (deserializeJson(doc, msg) != DeserializationError::Ok) {
    Serial.println("[SLAVE] Erreur parsing JSON");
    return;
  }

  String t = doc["type"];

  if (t == "assigned") {
    slotId = doc["slotId"];
    Serial.printf("[SLAVE] Slot assigné: %d\n", slotId);
    updateLEDs();
    updateLocalDisplay();
  } else if (t == "identify") {
    Serial.println("[SLAVE] Demande d'identification reçue");
    sendRegister();
  } else if (t == "update_info") {
    String p = doc["prenom"].as<String>();
    String n = doc["nom"].as<String>();

    if (xSemaphoreTake(xMutex, 500)) {
      monPrenom = p;
      monNom = n;
      xSemaphoreGive(xMutex);

      sauvegarderNom(p, n);
      sendRegister();
    }
  }
}

void changedConnectionCallback() {
  auto nodes = mesh.getNodeList();
  Serial.printf("[SLAVE] Connexions changées! Nodes: %d\n", nodes.size());

  // Vérification plus robuste: utiliser isConnected() si disponible
  // ou vérifier si le mesh est toujours actif
  bool isConnected = mesh.isConnected(mesh.getNodeId()) || !nodes.empty();

  if (!isConnected && slotId != -1) {
    Serial.println("[SLAVE] Déconnecté du mesh - Reset slotId");
    slotId = -1;
    updateLEDs();
    updateLocalDisplay();
  } else if (isConnected || !nodes.empty()) {
    Serial.println("[SLAVE] Connecté au mesh - Envoi register différé");
    // Différer l'envoi pour éviter les problèmes dans le callback
    needsRegister = true; // Sera traité par la tâche principale
  }
}
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
void loop() { vTaskDelay(1000); }

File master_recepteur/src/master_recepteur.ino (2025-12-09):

/*
 * ═══════════════════════════════════════════════════════════════════════════════
 * ESP32 MASTER RÉCEPTEUR - DispoMesh v6.0 ENHANCED
 * ═══════════════════════════════════════════════════════════════════════════════
 * NOUVELLES FONCTIONNALITÉS:
 *   ✓ Anti-clignotement (cache displays)
 *   ✓ Detection écrans détachables I2C
 *   ✓ Animations de transition fluides
 *   ✓ Historique des statuts
 *   ✓ API REST complète
 *   ✓ Dashboard web amélioré avec QR Code
 * ═══════════════════════════════════════════════════════════════════════════════
 */

#include <ArduinoJson.h>
#include <painlessMesh.h>
#include <Wire.h>
#include <Adafruit_GFX.h>
#include <Adafruit_SSD1306.h>
#include <U8g2_for_Adafruit_GFX.h>
#include <WiFi.h>
#include <WebServer.h>
#include <SPIFFS.h>
#include <Adafruit_NeoPixel.h>
#include <esp_task_wdt.h>

// MODULES CRITIQUES
#include "soc/soc.h"
#include "soc/rtc_cntl_reg.h"

// Config CONFIGURATION MESH
#define MESH_PREFIX     "DispoMesh"
#define MESH_PASSWORD   "meshpass2025"
#define MESH_PORT       5555
#define MESH_CHANNEL    6

// Anim CONFIGURATION ANIMATIONS
#define SCROLL_SPEED      2.5f
#define ANIMATION_FPS     30
#define FRAME_DELAY       (1000 / ANIMATION_FPS)
#define SCREEN_CHECK_MS   5000
#define HISTORY_MAX       20
#define HEARTBEAT_TIMEOUT_MS 60000  // 60 secondes sans heartbeat = déconnexion

#define SCREEN_WIDTH 128
#define SCREEN_HEIGHT 32
#define OLED_ADDR     0x3C
#define TCA_ADDR      0x70

#define PIN_NEOPIXEL  27
#define PIXELS_PER_SLOT 1
constexpr uint8_t MAX_SLOTS = 5;
#define TOTAL_PIXELS  (MAX_SLOTS * PIXELS_PER_SLOT)

Adafruit_NeoPixel strip(TOTAL_PIXELS, PIN_NEOPIXEL, NEO_GRB + NEO_KHZ800);
const uint8_t canaux[MAX_SLOTS] = {0, 1, 2, 3, 5};

const uint32_t C_DISPO = strip.Color(0, 255, 0);
const uint32_t C_BUSY  = strip.Color(255, 0, 0);
const uint32_t C_AWAY  = strip.Color(255, 140, 0);
const uint32_t C_OFF   = strip.Color(10, 10, 10);

// Screen Cache displays (anti-clignotement)
Adafruit_SSD1306* displays[MAX_SLOTS] = {nullptr};
U8G2_FOR_ADAFRUIT_GFX* u8g2Cache[MAX_SLOTS] = {nullptr};
bool screenPresent[MAX_SLOTS] = {false};

// History Structure historique
struct HistoryEntry {
  unsigned long timestamp;
  int oldState;
  int newState;
};

struct PersonInfo {
  uint32_t nodeId = 0;
  String prenom = "---";
  String nom = "---";
  int etat = 2;
  bool connecte = false;
  
  // Heartbeat tracking
  unsigned long lastHeartbeat = 0;
  bool ecoMode = false;
  
  // Animation scrolling
  float scrollPos = 0;
  bool needsScroll = false;
  int textWidth = 0;
  bool dirty = true;
  
  // Animation transition
  int prevEtat = 2;
  uint8_t transitionFrame = 0;
  bool inTransition = false;
  
  // Historique circulaire
  HistoryEntry history[HISTORY_MAX];
  uint8_t historyIdx = 0;
  uint8_t historyCount = 0;
};

PersonInfo persons[MAX_SLOTS];
SemaphoreHandle_t xMutex;
Scheduler userScheduler;
painlessMesh mesh;
WebServer server(80);

unsigned long lastScreenCheck = 0;
unsigned long bootTime = 0;

// Historique global pour l'API
struct GlobalHistoryEntry {
  unsigned long timestamp;
  uint8_t slot;
  int oldState;
  int newState;
};
#define GLOBAL_HISTORY_MAX 30
GlobalHistoryEntry globalHistory[GLOBAL_HISTORY_MAX];
uint8_t globalHistoryIdx = 0;
uint8_t globalHistoryCount = 0;

// Icônes
const unsigned char icon_wifi[] PROGMEM = { 0x3C, 0x42, 0x81, 0x3C, 0x42, 0x18, 0x00, 0x18 };
const unsigned char icon_disconn[] PROGMEM = { 0x00, 0x42, 0x24, 0x18, 0x18, 0x24, 0x42, 0x00 };

// Prototypes pour éviter les erreurs de compilation PlatformIO
void recoverI2C();
bool tcaSelect(uint8_t i);
bool isScreenPresent(uint8_t channel);
bool initScreen(uint8_t idx);
void checkScreens();
void addHistory(uint8_t idx, int oldState, int newState);
void updateLEDs();
void drawScreen(uint8_t idx);
void saveDb(uint32_t id, String p, String n);
int findSlot(uint32_t id);
int findFree();
void receivedCallback(uint32_t from, String &msg);
void changed();
void taskRun(void *p);
void playStartupAnimation();
void checkScreenSaver();

void recoverI2C() { Wire.end(); delay(10); Wire.begin(); Wire.setClock(400000); Wire.setTimeOut(1000); }
bool tcaSelect(uint8_t i) {
  if (i>7) return false;
  Wire.beginTransmission(TCA_ADDR); Wire.write(1<<i); 
  if(Wire.endTransmission()!=0) { recoverI2C(); return false; }
  return true;
}

// Screen Detection d'écran I2C sur un canal
bool isScreenPresent(uint8_t channel) {
  if (!tcaSelect(channel)) return false;
  Wire.beginTransmission(OLED_ADDR);
  return (Wire.endTransmission() == 0);
}

// Screen Initialisation d'un écran (cache anti-flicker)
bool initScreen(uint8_t idx) {
  if (!tcaSelect(canaux[idx])) return false;
  if (displays[idx] != nullptr) {
    delete u8g2Cache[idx];
    delete displays[idx];
  }
  displays[idx] = new Adafruit_SSD1306(SCREEN_WIDTH, SCREEN_HEIGHT, &Wire, -1);
  if (!displays[idx]->begin(SSD1306_SWITCHCAPVCC, OLED_ADDR)) {
    delete displays[idx];
    displays[idx] = nullptr;
    return false;
  }
  u8g2Cache[idx] = new U8G2_FOR_ADAFRUIT_GFX();
  u8g2Cache[idx]->begin(*displays[idx]);
  u8g2Cache[idx]->setFont(u8g2_font_unifont_t_symbols);
  u8g2Cache[idx]->setForegroundColor(SSD1306_WHITE);
  screenPresent[idx] = true;
  Serial.printf("[SCREEN] Ecran %d initialisé\n", idx);
  return true;
}

// Screen Vérification périodique des écrans (hot-plug)
void checkScreens() {
  for (uint8_t i = 0; i < MAX_SLOTS; i++) {
    bool present = isScreenPresent(canaux[i]);
    if (present && !screenPresent[i]) {
      Serial.printf("[SCREEN] Ecran %d detecté!\n", i);
      if (initScreen(i)) persons[i].dirty = true;
    } else if (!present && screenPresent[i]) {
      Serial.printf("[SCREEN] Ecran %d deconnecté\n", i);
      screenPresent[i] = false;
      if (displays[i] != nullptr) {
        delete u8g2Cache[i]; delete displays[i];
        displays[i] = nullptr; u8g2Cache[i] = nullptr;
      }
    }
  }
}

// History Ajout historique (local par personne + global pour API)
void addHistory(uint8_t idx, int oldState, int newState) {
  if (idx >= MAX_SLOTS) return;
  PersonInfo& p = persons[idx];
  p.history[p.historyIdx].timestamp = millis();
  p.history[p.historyIdx].oldState = oldState;
  p.history[p.historyIdx].newState = newState;
  p.historyIdx = (p.historyIdx + 1) % HISTORY_MAX;
  if (p.historyCount < HISTORY_MAX) p.historyCount++;
  
  // Ajout à l'historique global
  globalHistory[globalHistoryIdx].timestamp = millis();
  globalHistory[globalHistoryIdx].slot = idx;
  globalHistory[globalHistoryIdx].oldState = oldState;
  globalHistory[globalHistoryIdx].newState = newState;
  globalHistoryIdx = (globalHistoryIdx + 1) % GLOBAL_HISTORY_MAX;
  if (globalHistoryCount < GLOBAL_HISTORY_MAX) globalHistoryCount++;
}
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

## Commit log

2025-12-01 Initial commit: DispoMesh v6.0 - Système de disponibilité ESP32
2025-12-01 Update README: Correct repo URL, add Arduino IDE option and image placeholders
2025-12-02 Fix du script de deploiment et augmentation du delai de Watchdog pour une meilleure stabilitée.
    [master_recepteur.ino, slave_emetteur.ino]
2025-12-04 Amélioration de la gestion des mutex et des envois de données
    - Augmentation du timeout pour la prise de mutex lors de l'envoi de données.
    - Ajout d'un gestionnaire pour les pages non trouvées dans le serveur web.
    - Optimisation de la gestion des informations reçues avec des vérifications de mutex.
    - Désactivation de l'économie d'énergie WiFi pour améliorer la stabilité.
    - Suppression de la réinitialisation du watchdog pour éviter des redémarrages intempestifs.
2025-12-08 Fix: Correction de l'initialisation du SSID et de la validation de configuration
    - Utilisation de ESP.getEfuseMac() pour un SSID stable
    - Correction de la logique de sauvegarde et chargement pour éviter l'écrasement du nom
    - Ajout de validations pour empêcher l'utilisation de l'SSID comme prénom
    [slave_emetteur.ino]
2025-12-09 Feat: Integration des ressources web dans le code (Embedded) pour master_recepteur v6.1
2025-12-09 Fix des slots I2C
    [master_recepteur.ino]
2025-12-15 Ajoute des Photos et videos de presentation du projet.
2025-12-16 Ajout des modés
    [Emetteur_Base.STL, Emetteur_Boite.STL, Piece 1.SLDPRT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]

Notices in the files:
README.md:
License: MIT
